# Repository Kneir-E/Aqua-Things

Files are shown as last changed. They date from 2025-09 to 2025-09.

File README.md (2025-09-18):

- **Aqua_Things_V2**
  - Arduino IDE platform  
  - Contains the latest version of the Main Device contents *(this is the latest that I can find, I lost copy to the actual final version)*
- **ESP8266_Calibration-Module**
  - Arduino IDE platform  
  - Contains the code for the Calibration Module
- **KiCad Files**
  - **3.1) ESP_Board_Test**  
    - KiCad Schematics for the main board of the device
  - **3.2) ESP8266_Calib_Module**  
    - KiCad Schematics for the calibration module board
  - **3.3) KiCad Extras-Libraries-etc**  
    - Libraries used for the creation of 3.1 and 3.2
- **Ignore the rest of the folders**
- **4) Old Version** → Ignore
- **5) Helper for testing - Lux-Web** → Ignore
- **6) Helper for testing - Temperature-Web** → Ignore

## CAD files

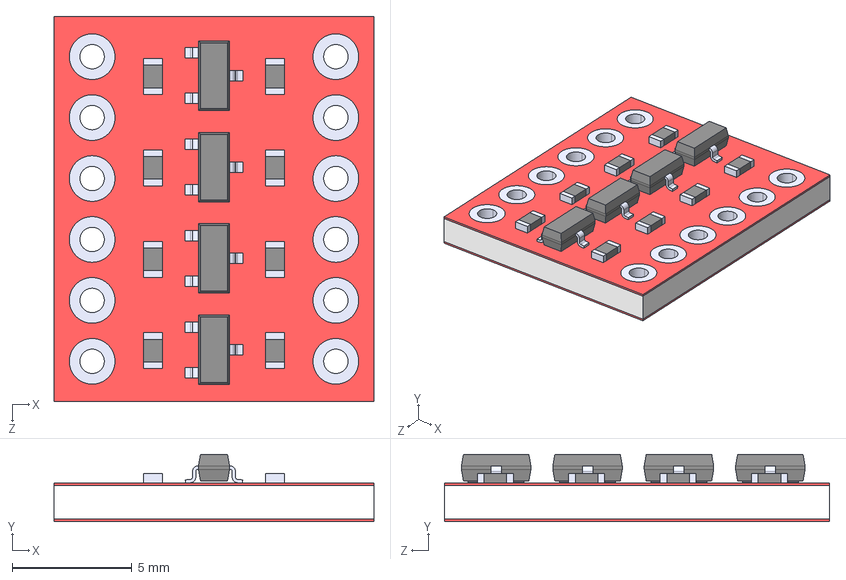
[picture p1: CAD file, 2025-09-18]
KiCad Files/KiCad Extras-Libraries-etc/BOB-12009/BOB-12009.step
13.3 x 2.80 x 16.1 mm

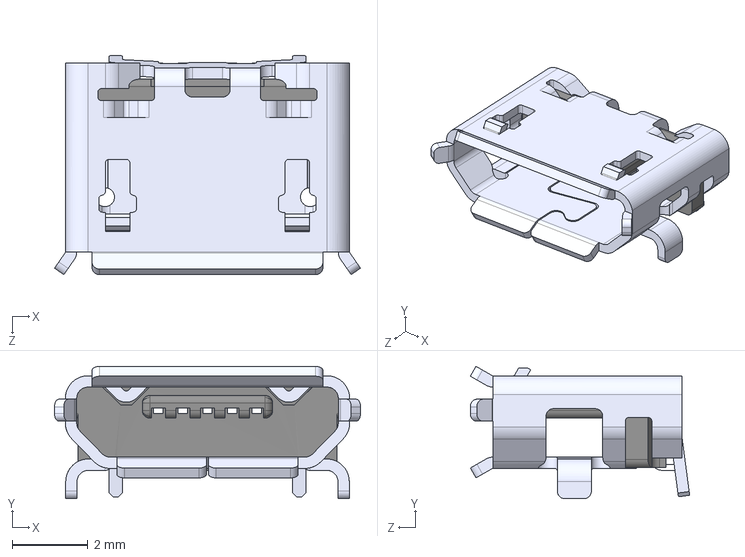
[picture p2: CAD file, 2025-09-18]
KiCad Files/KiCad Extras-Libraries-etc/MicroUSB/ZX62D-B-5P8.step
8.09 x 3.50 x 5.80 mm

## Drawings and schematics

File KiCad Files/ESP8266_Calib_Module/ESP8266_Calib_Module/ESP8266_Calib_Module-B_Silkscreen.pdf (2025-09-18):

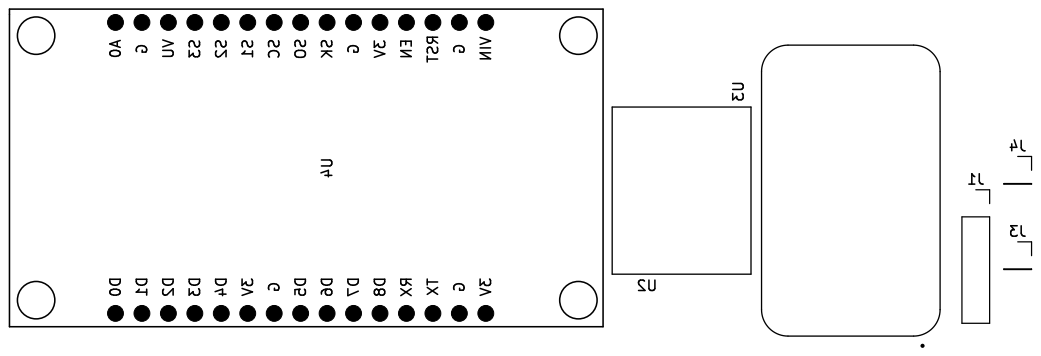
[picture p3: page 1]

J3 U4 SK RST D2 D3GRX VU 3V 3V D0 A0 SO D6 D7TX S2S1EN G G D5 S3SC D4 D8 VING D13V G

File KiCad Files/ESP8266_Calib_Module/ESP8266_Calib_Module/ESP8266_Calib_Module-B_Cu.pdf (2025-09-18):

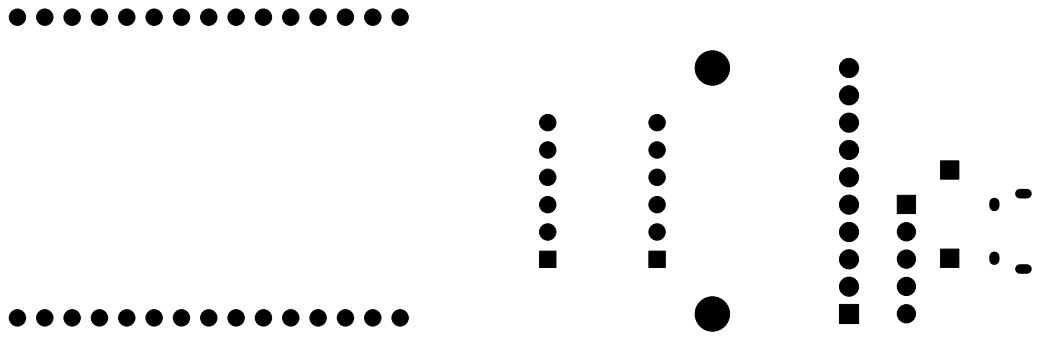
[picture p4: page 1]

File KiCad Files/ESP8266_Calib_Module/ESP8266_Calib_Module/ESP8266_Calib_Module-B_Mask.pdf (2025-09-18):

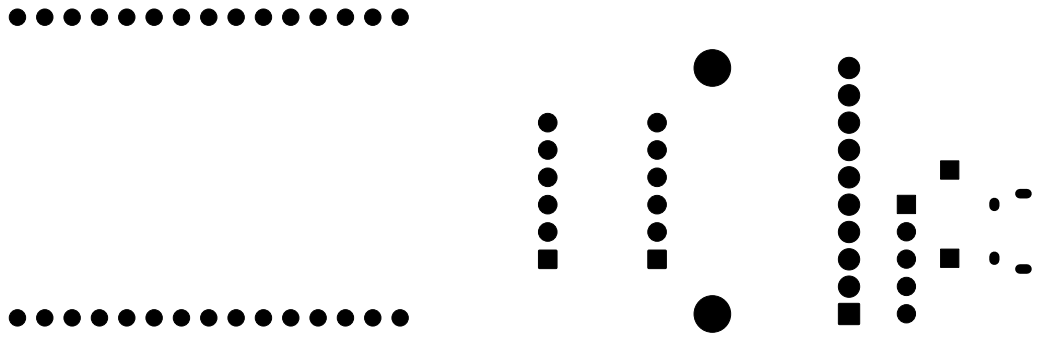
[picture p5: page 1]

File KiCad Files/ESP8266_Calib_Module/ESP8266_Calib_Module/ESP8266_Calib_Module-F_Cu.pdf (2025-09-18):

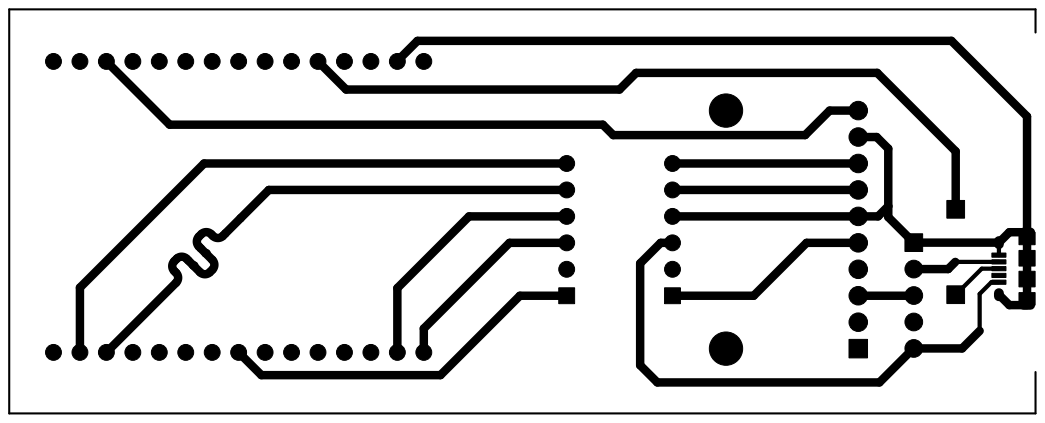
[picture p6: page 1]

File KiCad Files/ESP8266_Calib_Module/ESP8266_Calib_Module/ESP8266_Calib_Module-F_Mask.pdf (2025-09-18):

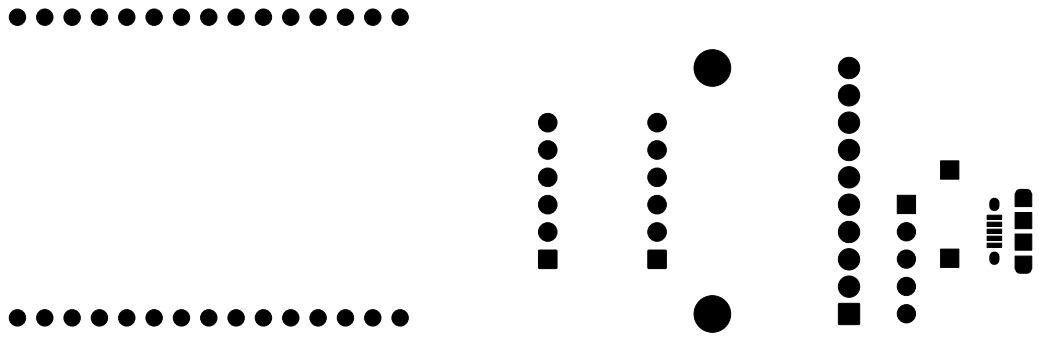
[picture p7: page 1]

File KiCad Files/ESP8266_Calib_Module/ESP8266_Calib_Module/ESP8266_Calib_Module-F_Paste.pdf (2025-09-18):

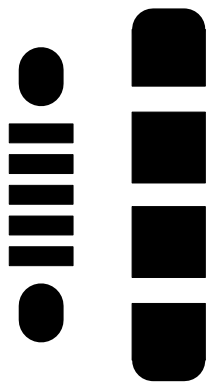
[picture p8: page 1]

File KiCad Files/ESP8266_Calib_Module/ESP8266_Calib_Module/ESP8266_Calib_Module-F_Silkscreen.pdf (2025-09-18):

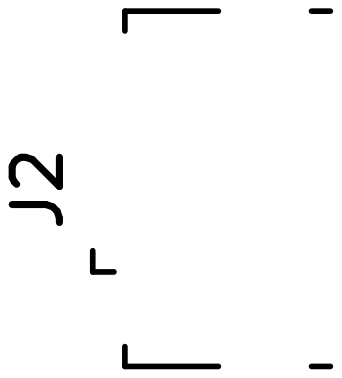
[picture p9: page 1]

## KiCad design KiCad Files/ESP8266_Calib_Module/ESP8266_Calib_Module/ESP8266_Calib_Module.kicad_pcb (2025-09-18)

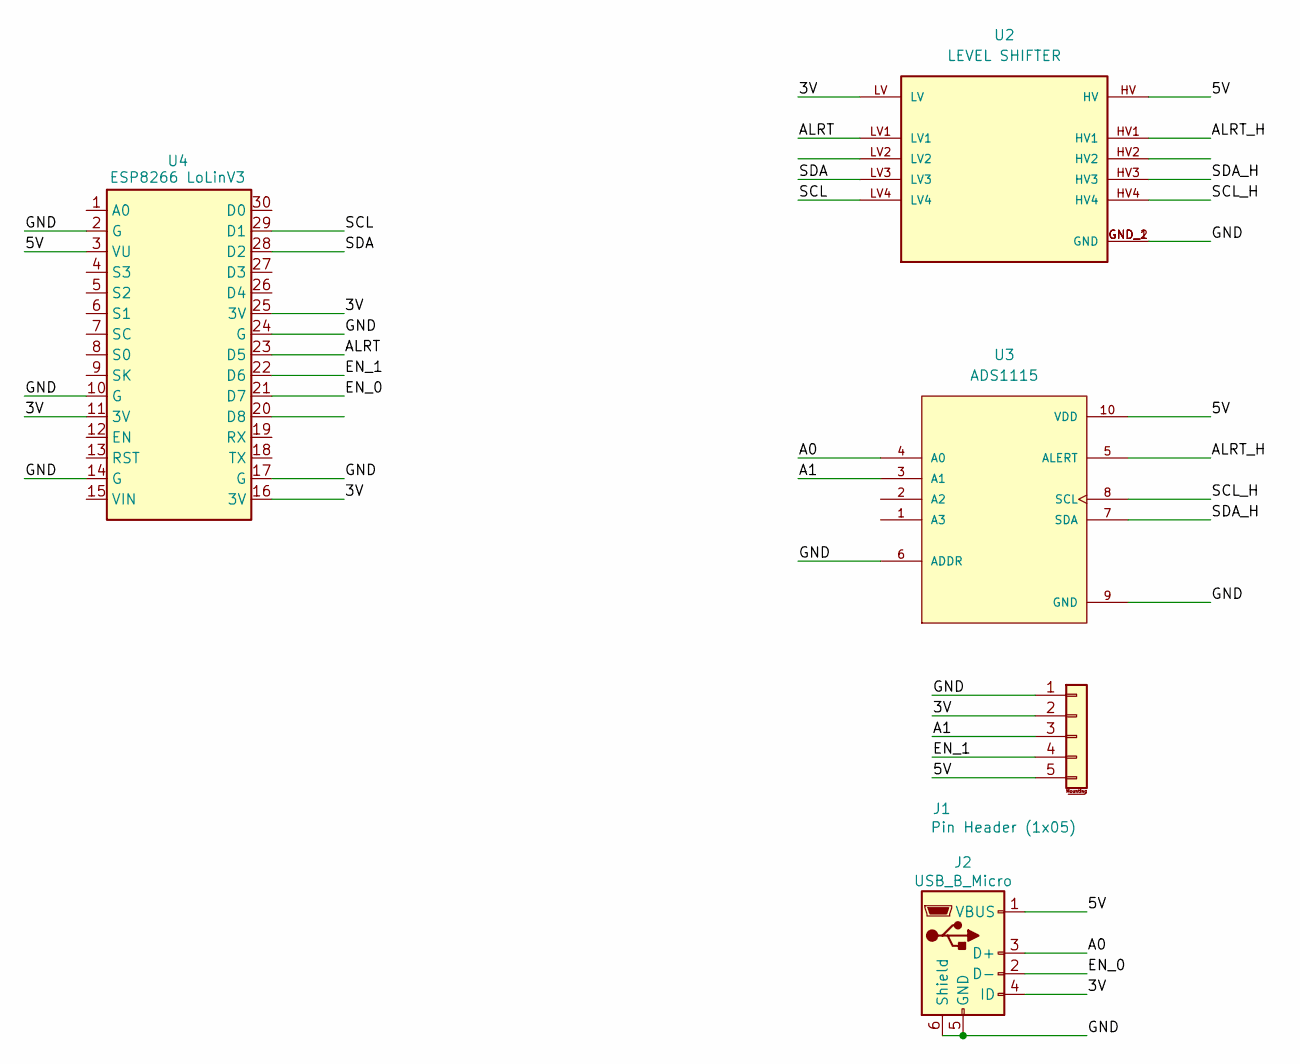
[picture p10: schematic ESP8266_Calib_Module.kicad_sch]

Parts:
J1: Pin Header (1x05); PinHeader_1x05_P2.54mm_Vertical
J2: USB_B_Micro; USB_Micro-B_Amphenol_10118194_Horizontal
U2: LEVEL SHIFTER; CONV_BOB-12009; PARTREV 01
U3: ADS1115; MODULE_ZC261500; PARTREV NA
U4: ESP8266 LoLinV3; NodeMCU-LoLinV3

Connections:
/3V: J1.2, J2.4 (ID), U2.LV, U4.11 (3V), U4.16 (3V), U4.25 (3V)
/5V: J1.5, J2.1 (VBUS), U2.HV, U3.10 (VDD), U4.3 (VU)
/A0: J2.3 (D+), U3.4 (A0)
/A1: J1.3, U3.3 (A1)
/ALRT: U2.LV1, U4.23 (D5)
/ALRT_H: U2.HV1, U3.5 (ALERT)
/EN_0: J2.2 (D-), U4.21 (D7)
/EN_1: J1.4, U4.22 (D6)
/GND: J1.1, J2.5 (GND), J2.6 (Shield), U2.GND_1 (GND), U2.GND_2 (GND), U3.6 (ADDR), U3.9 (GND), U4.2 (G), U4.10 (G), U4.14 (G), U4.17 (G), U4.24 (G)
/SCL: U2.LV4, U4.29 (D1)
/SCL_H: U2.HV4, U3.8 (SCL)
/SDA: U2.LV3, U4.28 (D2)
/SDA_H: U2.HV3, U3.7 (SDA)

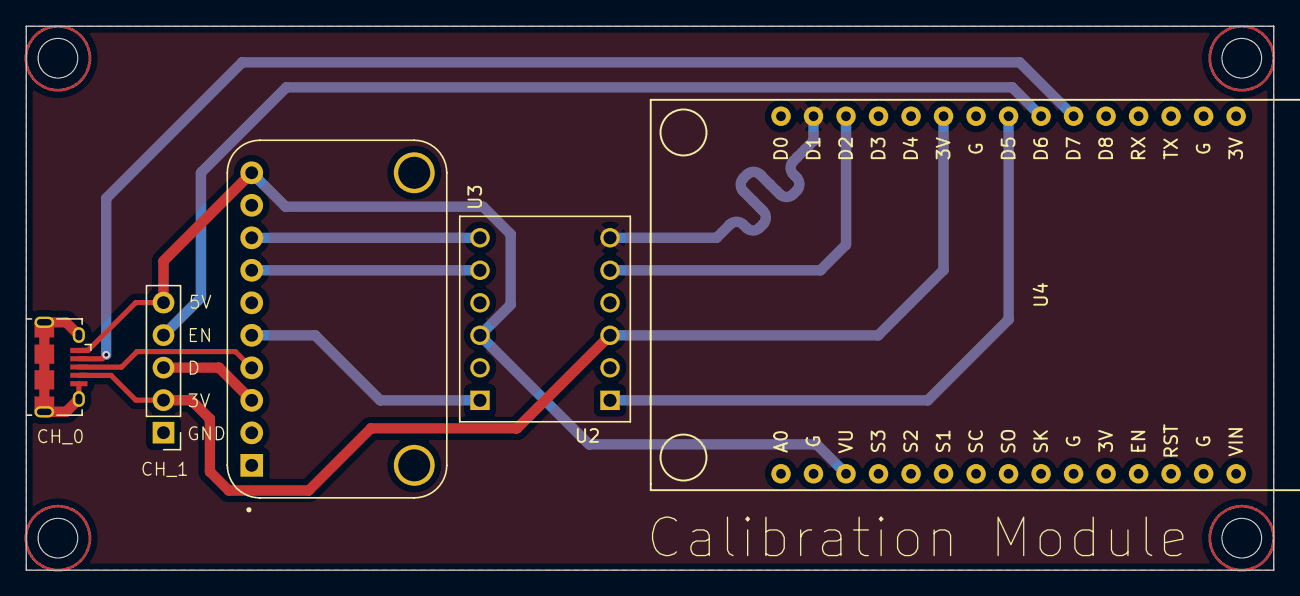
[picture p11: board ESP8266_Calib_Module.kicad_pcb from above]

Board: 2 copper layers, 97.5 x 42.5 mm, 5 parts (0 on the bottom side), 13 nets.

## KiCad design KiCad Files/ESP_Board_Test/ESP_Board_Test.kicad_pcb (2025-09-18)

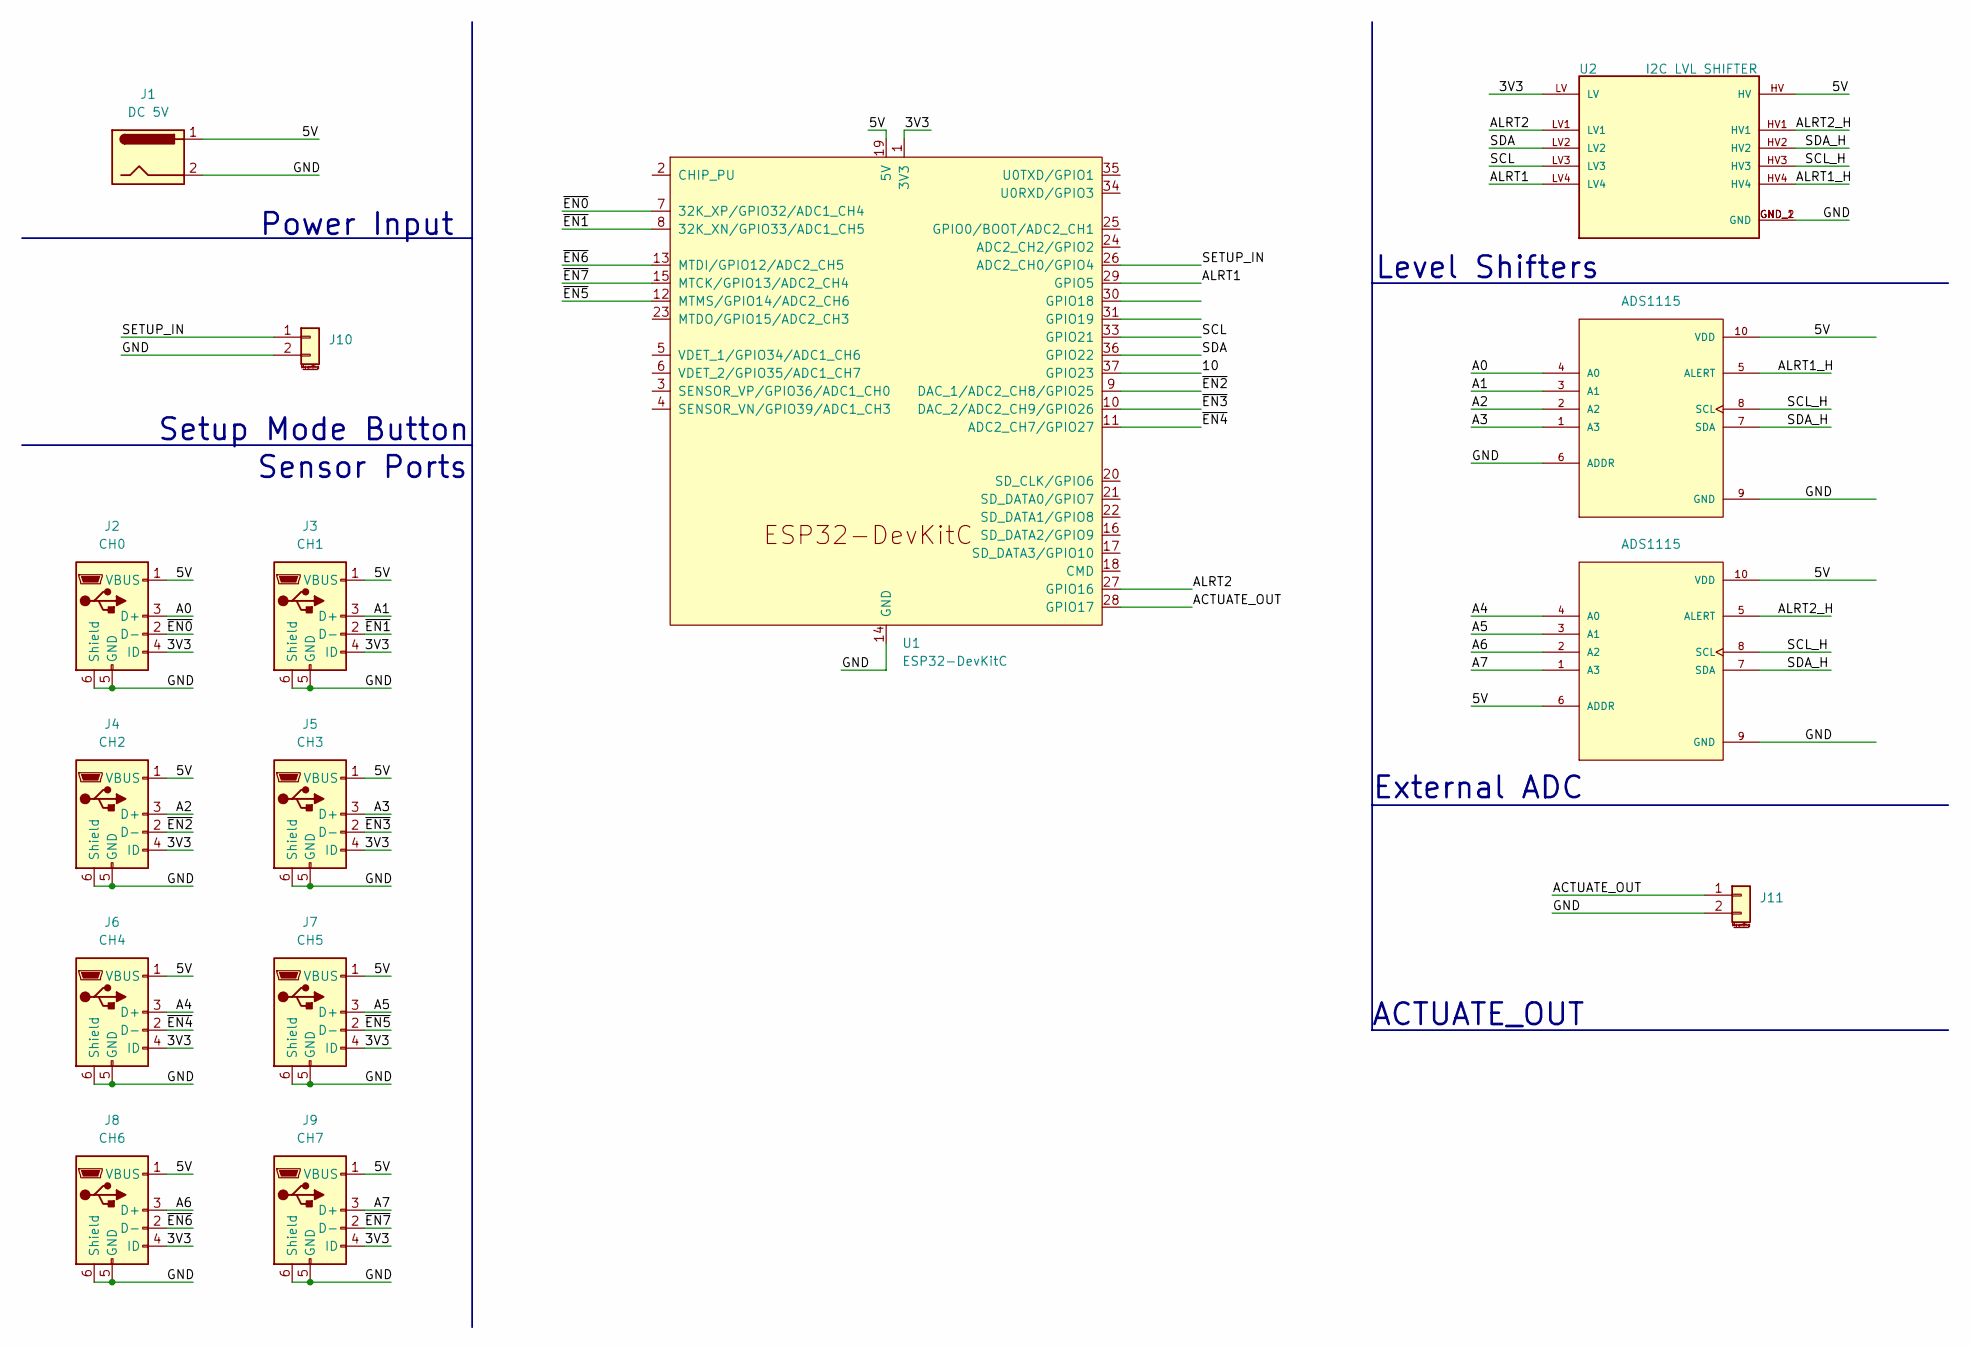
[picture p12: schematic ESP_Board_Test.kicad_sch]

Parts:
J1: DC 5V; BarrelJack_Horizontal
J2: CH0; USB_Micro-B_Amphenol_10118194_Horizontal
J3: CH1; USB_Micro-B_Amphenol_10118194_Horizontal
J4: CH2; USB_Micro-B_Amphenol_10118194_Horizontal
J5: CH3; USB_Micro-B_Amphenol_10118194_Horizontal
J6: CH4; USB_Micro-B_Amphenol_10118194_Horizontal
J7: CH5; USB_Micro-B_Amphenol_10118194_Horizontal
J8: CH6; USB_Micro-B_Amphenol_10118194_Horizontal
J9: CH7; USB_Micro-B_Amphenol_10118194_Horizontal
J10, J11: Pin Header; PinHeader_1x02_P2.54mm_Vertical
U1: ESP32-DevKitC
U2: I2C LVL SHIFTER; CONV_BOB-12009; PARTREV 01
U4, U5: ADS1115; MODULE_ZC261500; PARTREV NA

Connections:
/3V3: J2.4 (ID), J3.4 (ID), J4.4 (ID), J5.4 (ID), J6.4 (ID), J7.4 (ID), J8.4 (ID), J9.4 (ID), U1.1 (3V3), U2.LV
/5V: J1.1, J2.1 (VBUS), J3.1 (VBUS), J4.1 (VBUS), J5.1 (VBUS), J6.1 (VBUS), J7.1 (VBUS), J8.1 (VBUS), J9.1 (VBUS), U1.19 (5V), U2.HV, U4.10 (VDD), U5.6 (ADDR), U5.10 (VDD)
/10: U1.37 (GPIO23)
/A0: J2.3 (D+), U4.4 (A0)
/A1: J3.3 (D+), U4.3 (A1)
/A2: J4.3 (D+), U4.2 (A2)
/A3: J5.3 (D+), U4.1 (A3)
/A4: J6.3 (D+), U5.4 (A0)
/A5: J7.3 (D+), U5.3 (A1)
/A6: J8.3 (D+), U5.2 (A2)
/A7: J9.3 (D+), U5.1 (A3)
/ACTUATE_OUT: J11.1, U1.28 (GPIO17)
/ALRT1: U1.29 (GPIO5), U2.LV4
/ALRT1_H: U2.HV4, U4.5 (ALERT)
/ALRT2: U1.27 (GPIO16), U2.LV1
/ALRT2_H: U2.HV1, U5.5 (ALERT)
/GND: J1.2, J2.5 (GND), J2.6 (Shield), J3.5 (GND), J3.6 (Shield), J4.5 (GND), J4.6 (Shield), J5.5 (GND), J5.6 (Shield), J6.5 (GND), J6.6 (Shield), J7.5 (GND), J7.6 (Shield), J8.5 (GND), J8.6 (Shield), J9.5 (GND), J9.6 (Shield), J10.2, J11.2, U1.14 (GND), U1.32 (GND), U1.38 (GND), U2.GND_1 (GND), U2.GND_2 (GND), U4.6 (ADDR), U4.9 (GND), U5.9 (GND)
/SCL: U1.33 (GPIO21), U2.LV3
/SCL_H: U2.HV3, U4.8 (SCL), U5.8 (SCL)
/SDA: U1.36 (GPIO22), U2.LV2
/SDA_H: U2.HV2, U4.7 (SDA), U5.7 (SDA)
/SETUP_IN: J10.1, U1.26 (ADC2_CH0/GPIO4)
/~EN0: J2.2 (D-), U1.7 (32K_XP/GPIO32/ADC1_CH4)
/~EN1: J3.2 (D-), U1.8 (32K_XN/GPIO33/ADC1_CH5)
/~EN2: J4.2 (D-), U1.9 (DAC_1/ADC2_CH8/GPIO25)
/~EN3: J5.2 (D-), U1.10 (DAC_2/ADC2_CH9/GPIO26)
/~EN4: J6.2 (D-), U1.11 (ADC2_CH7/GPIO27)
/~EN5: J7.2 (D-), U1.12 (MTMS/GPIO14/ADC2_CH6)
/~EN6: J8.2 (D-), U1.13 (MTDI/GPIO12/ADC2_CH5)
/~EN7: J9.2 (D-), U1.15 (MTCK/GPIO13/ADC2_CH4)

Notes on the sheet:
Sensor Ports
Power Input
ACTUATE_OUT
External ADC
Level Shifters
Setup Mode Button

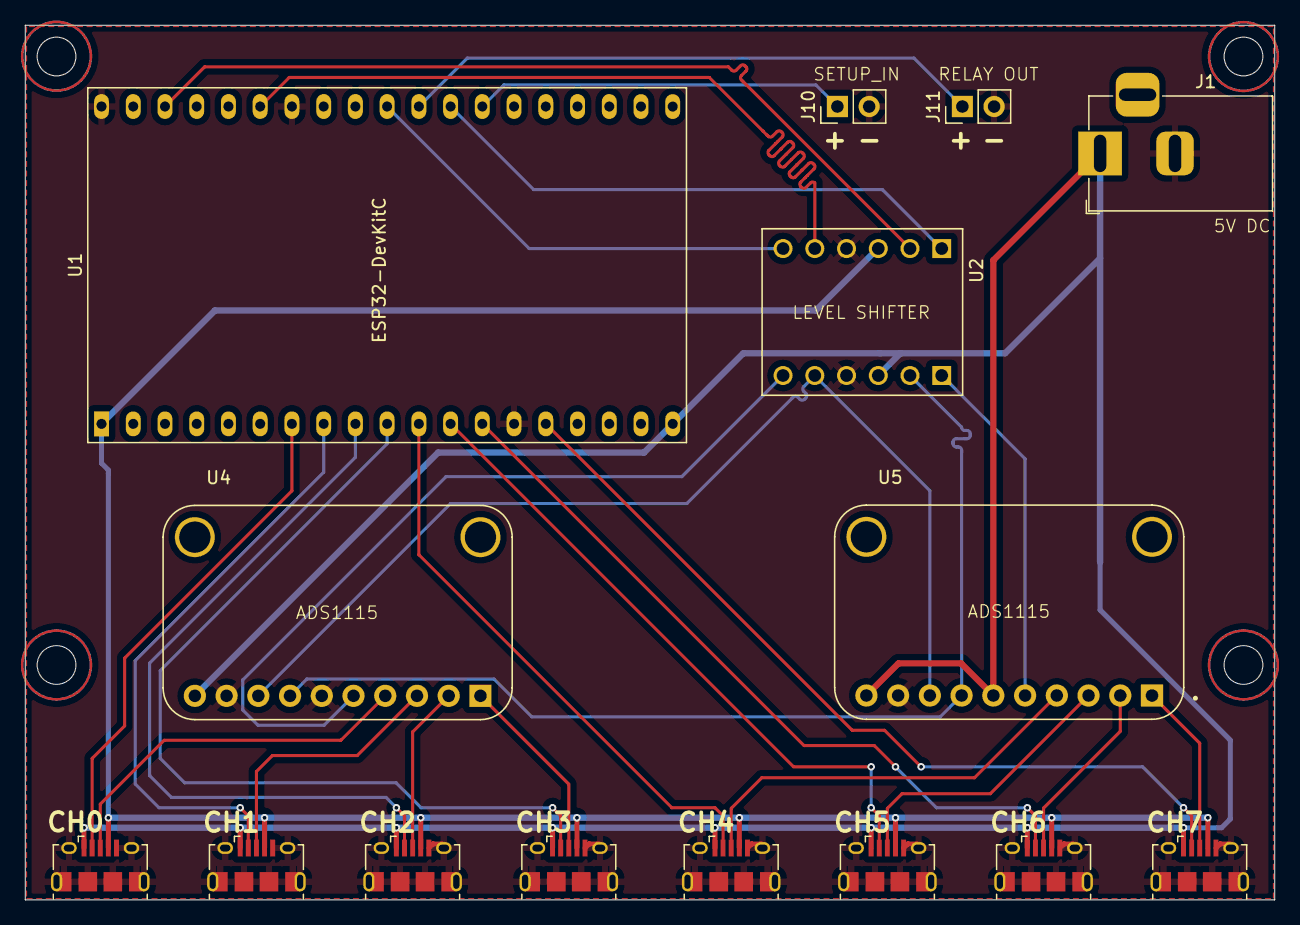
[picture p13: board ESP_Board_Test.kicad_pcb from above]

Board: 2 copper layers, 100.0 x 70.0 mm, 15 parts (0 on the bottom side), 29 nets.

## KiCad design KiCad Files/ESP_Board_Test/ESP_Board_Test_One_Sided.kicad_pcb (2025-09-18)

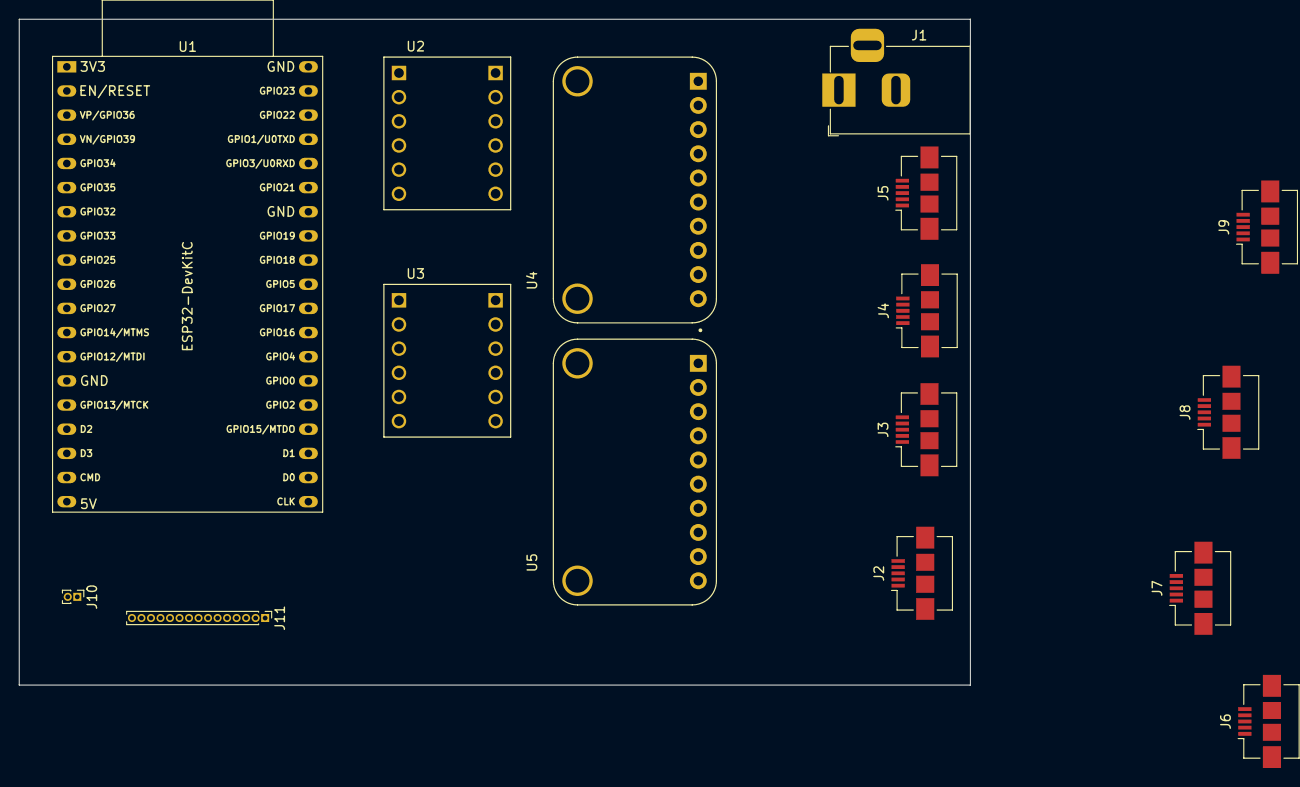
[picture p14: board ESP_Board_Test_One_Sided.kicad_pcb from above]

Board: 2 copper layers, 100.0 x 70.0 mm, 16 parts (0 on the bottom side), 34 nets, no tracks yet.

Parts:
J1: Barrel_Jack; BarrelJack_Horizontal
J2, J3, J4, J5, J6, J7, J8, J9: USB_B_Micro; USB_Micro-B_Amphenol_10104110_Horizontal
J10: Conn_01x02_MountingPin; PinHeader_1x02_P1.00mm_Vertical
J11: Conn_01x15_MountingPin; PinHeader_1x15_P1.00mm_Vertical
U1: ESP32-DevKitC
U2, U3: BOB-12009; CONV_BOB-12009
U4, U5: ZC261500; MODULE_ZC261500

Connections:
/1: J11.15, U1.7 (32K_XP/GPIO32/ADC1_CH4)
/2: J11.14, U1.8 (32K_XN/GPIO33/ADC1_CH5)
/3: J11.13, U1.13 (MTDI/GPIO12/ADC2_CH5)
/3V3: J2.1 (VBUS), J3.1 (VBUS), J4.1 (VBUS), J5.1 (VBUS), J6.1 (VBUS), J7.1 (VBUS), J8.1 (VBUS), J9.1 (VBUS), U1.1 (3V3), U2.LV, U3.LV
/4: J11.12, U1.15 (MTCK/GPIO13/ADC2_CH4)
/5: J11.11, U1.12 (MTMS/GPIO14/ADC2_CH6)
/5V: J1.1, J2.2 (D-), J3.2 (D-), J4.2 (D-), J5.2 (D-), J6.2 (D-), J7.2 (D-), J8.2 (D-), J9.2 (D-), U1.19 (5V), U2.HV, U3.HV, U4.10 (VDD), U5.10 (VDD)
/6: J11.10, U1.26 (ADC2_CH0/GPIO4)
/7: J11.9, U1.29 (GPIO5)
/8: J11.8, U1.30 (GPIO18)
/9: J11.7, U1.31 (GPIO19)
/10: J11.6, U1.37 (GPIO23)
/11: J11.5, U1.9 (DAC_1/ADC2_CH8/GPIO25)
/12: J11.4, U1.10 (DAC_2/ADC2_CH9/GPIO26)
/13: J11.3, U1.11 (ADC2_CH7/GPIO27)
/14: J11.2, U1.27 (GPIO16)
/15: J11.1, U1.28 (GPIO17)
/A0: J2.3 (D+), U4.4 (A0)
/A1: J3.3 (D+), U4.3 (A1)
/A2: J4.3 (D+), U4.2 (A2)
/A3: J5.3 (D+), U4.1 (A3)
/A4: J6.3 (D+), U5.4 (A0)
/A5: J7.3 (D+), U5.3 (A1)
/A6: J8.3 (D+), U5.2 (A2)
/A7: J9.3 (D+), U5.1 (A3)
/ADDR1_H: U2.HV2, U4.6 (ADDR)
/ADDR2_H: U3.HV4, U5.6 (ADDR)
/ALRT1_H: U2.HV1, U4.5 (ALERT)
/ALRT2_H: U3.HV3, U5.5 (ALERT)
/GND: J1.2, J2.5 (GND), J3.5 (GND), J4.5 (GND), J5.5 (GND), J6.5 (GND), J7.5 (GND), J8.5 (GND), J9.5 (GND), J10.2, U1.14 (GND), U1.32 (GND), U1.38 (GND), U2.GND_1 (GND), U2.GND_2 (GND), U3.GND_1 (GND), U3.GND_2 (GND), U4.9 (GND), U5.9 (GND)
/SCL: U1.33 (GPIO21), U3.LV2
/SCL_H: U3.HV2, U4.8 (SCL), U5.8 (SCL)
/SDA: U1.36 (GPIO22), U3.LV1
/SDA_H: U3.HV1, U4.7 (SDA), U5.7 (SDA)

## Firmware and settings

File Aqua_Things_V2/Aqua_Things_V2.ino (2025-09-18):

#include <WiFi.h>
#include <String.h>
#include "ConfigManager.h"
#include "ADS_functions.h"
#include "Preferences_functions.h"
#include "SocketClient.h"

// === Config Variables: Used in other header files ===
String STA_SSID = "";
String STA_PASS = "";
String STA_HOST = "";
String STA_PORT = "";
String AP_SSID = "";
String AP_PASS = "";
String PKT_HEAD = "";
String PKT_TAIL = "";
bool P0_ACTU_EN = false;
bool P1_ACTU_EN = false;
bool P2_ACTU_EN = false;
bool P3_ACTU_EN = false;
bool P4_ACTU_EN = false;
bool P5_ACTU_EN = false;
bool P6_ACTU_EN = false;
bool P7_ACTU_EN = false;
int P0_ACTU_L = -9999;  // Port 0 Actuation Value Low (actuate if measurement is below)
int P1_ACTU_L = -9999;  // Port 1                         ''
int P2_ACTU_L = -9999;  // Port 2                         ''
int P3_ACTU_L = -9999;  // Port 3                         ''
int P4_ACTU_L = -9999;  // Port 4                         ''
int P5_ACTU_L = -9999;  // Port 5                         ''
int P6_ACTU_L = -9999;  // Port 6                         ''
int P7_ACTU_L = -9999;  // Port 7                         ''
int P0_ACTU_H = 9999;   // Port 0 Actuation Value High (actuate if measurement is above)
int P1_ACTU_H = 9999;   // Port 1                         ''
int P2_ACTU_H = 9999;   // Port 2                         ''
int P3_ACTU_H = 9999;   // Port 3                         ''
int P4_ACTU_H = 9999;   // Port 4                         ''
int P5_ACTU_H = 9999;   // Port 5                         ''
int P6_ACTU_H = 9999;   // Port 6                         ''
int P7_ACTU_H = 9999;   // Port 7                         ''
uint64_t DEVICE_ADDRESS = 0;
int SETUP_STATUS = DEVICE_SETUP_INIT;

#define PIN_DET0 32
#define PIN_DET1 33
#define PIN_DET2 25
#define PIN_DET3 26
#define PIN_DET4 27
#define PIN_DET5 14
#define PIN_DET6 12
#define PIN_DET7 13
#define ACTUATE_DURATION 300000
#define PIN_ACTU 17
bool actuate_Trig = false;
unsigned long actuate_Start_Time = 0;
unsigned long prev_send_Time = 0;

// === External ADC Objects ===
int adsCh0 = -1;
int adsCh1 = -1;
int adsCh2 = -1;
int adsCh3 = -1;
int adsCh4 = -1;
int adsCh5 = -1;
int adsCh6 = -1;
int adsCh7 = -1;


void cl_Handle_Msg() {
  if(millis() - prev_send_Time<1000)  //If 1 second has not passed since previous send time
    return;
  else
    prev_send_Time=millis();
  if (cl.available()) {
    String rcvmsg = cl.readStringUntil('\n');
    Serial.print("Received: ");
    Serial.println(rcvmsg);
    rcvmsg.trim();    //remove leading or trailing white space
    String command = rcvmsg.substring(0, 7);
    if (command == "Actu_On") {
      actuate_Start();
      cl.println("Actuating");
    } else if (command == "ActuOff") {
      actuate_End();
      cl.println("Actuation End");
    } else if (command == "SetActu") {
      Serial.println("Received command: Set Actuation");
      bool success = true;
      String params = rcvmsg.substring(7, rcvmsg.length());
      // Serial.println("Params: " + params);
      // Serial.println(params.charAt(0) == '-');
      while (params.charAt(0) == '-') {
        //  "-CH0H:9999-CH0L:0000-CH1H:0000-"
        //  "0123456789"
        String tmp = params.substring(1, 5);
        String val = params.substring(6, 10);
        // Serial.println("tmp: " + tmp);
        // Serial.println("val: " + val);
        int valInt;
        if (!(isDigit(val.charAt(0)) && isDigit(val.charAt(1)) && isDigit(val.charAt(2)) && isDigit(val.charAt(3)))) {
          success = false;
          break;
        }
        valInt = val.toInt();
        if (tmp.charAt(4) == 'L' && valInt == 0) valInt = -9999;
        if (tmp == "CH0L") P0_ACTU_L = valInt;
        else if (tmp == "CH1L") P1_ACTU_L = valInt;
        else if (tmp == "CH2L") P2_ACTU_L = valInt;
        else if (tmp == "CH3L") P3_ACTU_L = valInt;
        else if (tmp == "CH4L") P4_ACTU_L = valInt;
        else if (tmp == "CH5L") P5_ACTU_L = valInt;
        else if (tmp == "CH6L") P6_ACTU_L = valInt;
        else if (tmp == "CH7L") P7_ACTU_L = valInt;
        else if (tmp == "CH0H") P0_ACTU_H = valInt;
        else if (tmp == "CH1H") P1_ACTU_H = valInt;
        else if (tmp == "CH2H") P2_ACTU_H = valInt;
        else if (tmp == "CH3H") P3_ACTU_H = valInt;
        else if (tmp == "CH4H") P4_ACTU_H = valInt;
        else if (tmp == "CH5H") P5_ACTU_H = valInt;
        else if (tmp == "CH6H") P6_ACTU_H = valInt;
        else if (tmp == "CH7H") P7_ACTU_H = valInt;
        else {
          success = false;
          break;
        }
        params = params.substring(10, params.length());
      }
      if (success) {
        Serial.println("Successfuly Updated Actuation");
        cl.println("Successful");
        pf_Update();
      } else {
        Serial.println("Unsuccessful Update in Actuation");
        cl.println("Unuccessful");
        pf_Get();
      }
    } else if (command == "SetAcEn") {
      Serial.println("Received command: Set Actuation");
      bool success = true;
      String params = rcvmsg.substring(7, rcvmsg.length());
      Serial.println("Params: " + params);
      Serial.println(params.charAt(0) == '-');
      while (params.charAt(0) == '-') {
        //  "-CH0:1-"
        //  "0123456"
        String chn = params.substring(1, 4);
        char val = params.charAt(5);
        Serial.println("chn: " + chn);
        Serial.println("val: " + val);
  
        bool result;
        if(val=='1') result = true;
        else if(val=='0') result = false;
        else{
          success = false;
          break;
        }
        if      (chn == "CH0") P0_ACTU_EN = result;
        else if (chn == "CH1") P1_ACTU_EN = result;
        else if (chn == "CH2") P2_ACTU_EN = result;
        else if (chn == "CH3") P3_ACTU_EN = result;
        else if (chn == "CH4") P4_ACTU_EN = result;
        else if (chn == "CH5") P5_ACTU_EN = result;
        else if (chn == "CH6") P6_ACTU_EN = result;
        else if (chn == "CH7") P7_ACTU_EN = result;
        else {
          success = false;
          break;
        }
        params = params.substring(6, params.length());
      }
      if (success) {
        Serial.println("Successfuly Updated Actuation Enable");
        cl.println("Successful");
        pf_Update();
      } else {
        Serial.println("Unsuccessful Update in Actuation Enable");
        cl.println("Unuccessful");
        pf_Get();
      }
    }
  }
  String msg = String("{ ")
               + "\"CH0\": " + String(adsCh0) + ", " + "\"DET0\": " + String(digitalRead(PIN_DET0) == LOW) + ", "
               + "\"CH1\": " + String(adsCh1) + ", " + "\"DET1\": " + String(digitalRead(PIN_DET1) == LOW) + ", "
               + "\"CH2\": " + String(adsCh2) + ", " + "\"DET2\": " + String(digitalRead(PIN_DET2) == LOW) + ", "
               + "\"CH3\": " + String(adsCh3) + ", " + "\"DET3\": " + String(digitalRead(PIN_DET3) == LOW) + ", "
               + "\"CH4\": " + String(adsCh4) + ", " + "\"DET4\": " + String(digitalRead(PIN_DET4) == LOW) + ", "
               + "\"CH5\": " + String(adsCh5) + ", " + "\"DET5\": " + String(digitalRead(PIN_DET5) == LOW) + ", "
               + "\"CH6\": " + String(adsCh6) + ", " + "\"DET6\": " + String(digitalRead(PIN_DET6) == LOW) + ", "
               + "\"CH7\": " + String(adsCh7) + ", " + "\"DET7\": " + String(digitalRead(PIN_DET7) == LOW) + ", "
               + "\"ActuStat\": " + String(actuate_Trig) + "} ";

  cl.println(msg);
  Serial.println("Sent to Server: " + msg);
}

void config_Callback_On_Submit() {
  Serial.println("Callback Triggered on Submit");
  pf_Update();
  WiFi.softAPdisconnect();
  WiFi.disconnect(false, true);
  Serial.println(WiFi.status());
  Serial.println(WiFi.getMode());
  wifi_Init();
}

void port_Init() {
  Serial.println("Port Initialized");
  pinMode(PIN_DET0, INPUT_PULLUP);
  pinMode(PIN_DET1, INPUT_PULLUP);
  pinMode(PIN_DET2, INPUT_PULLUP);
  pinMode(PIN_DET3, INPUT_PULLUP);
  pinMode(PIN_DET4, INPUT_PULLUP);
  pinMode(PIN_DET5, INPUT_PULLUP);
  pinMode(PIN_DET6, INPUT_PULLUP);
  pinMode(PIN_DET7, INPUT_PULLUP);
  pinMode(PIN_ACTU, OUTPUT);
  digitalWrite(PIN_ACTU, HIGH);
}

void handle_Actu() {
  if (actuate_Trig) {
    if (millis() - actuate_Start_Time >= ACTUATE_DURATION) {
      actuate_End();
    }
    return;
  }
  if (P0_ACTU_EN && adsCh0 <= P0_ACTU_L) actuate_Start();
  if (P1_ACTU_EN && adsCh1 <= P1_ACTU_L) actuate_Start();
  if (P2_ACTU_EN && adsCh2 <= P2_ACTU_L) actuate_Start();
  if (P3_ACTU_EN && adsCh3 <= P3_ACTU_L) actuate_Start();
  if (P4_ACTU_EN && adsCh4 <= P4_ACTU_L) actuate_Start();
  if (P5_ACTU_EN && adsCh5 <= P5_ACTU_L) actuate_Start();
  if (P6_ACTU_EN && adsCh6 <= P6_ACTU_L) actuate_Start();
  if (P7_ACTU_EN && adsCh7 <= P7_ACTU_L) actuate_Start();

  if (P0_ACTU_EN && adsCh0 >= P0_ACTU_H) actuate_Start();
  if (P1_ACTU_EN && adsCh1 >= P1_ACTU_H) actuate_Start();
  if (P2_ACTU_EN && adsCh2 >= P2_ACTU_H) actuate_Start();
  if (P3_ACTU_EN && adsCh3 >= P3_ACTU_H) actuate_Start();
  if (P4_ACTU_EN && adsCh4 >= P4_ACTU_H) actuate_Start();
  if (P5_ACTU_EN && adsCh5 >= P5_ACTU_H) actuate_Start();
  if (P6_ACTU_EN && adsCh6 >= P6_ACTU_H) actuate_Start();
  if (P7_ACTU_EN && adsCh7 >= P7_ACTU_H) actuate_Start();
}

void actuate_Start() {
  if (actuate_Trig != true) {
    Serial.println("Actuation Started");
    digitalWrite(PIN_ACTU, LOW);
    actuate_Trig = true;
    actuate_Start_Time = millis();
  }
}

void actuate_End() {
  Serial.println("Actuation Ended");
  digitalWrite(PIN_ACTU, HIGH);
  actuate_Trig = false;
  actuate_Start_Time = 0;
}

void setup() {
  Serial.begin(115200);

  pf_Init();    // Retrieve Config Variables from ROM and store in RAM
  ads_Init();   // Initialize extenal ADC
  port_Init();  // Initialize port detection pins and actuation pin

  conf_Init(cl_Stop, config_Callback_On_Submit);  // Initialize Config Mode
                                                  // =======================ADD CALLBACKS... SHOULD BE AFTER WIFI===========================
                                                  // on trigger: close client
                                                  // on submit: pf_Update(), wifi_Init()

  if (is_Setup_Done == DEVICE_SETUP_NONE)  // IF DEVICE SETUP HAS NOT BEEN DONE
    __conf_trig_flag = true;               // Trigger Config Mode
}

void loop() {
  if (is_Setup_Done != DEVICE_SETUP_DONE) {  // IF DEVICE SETUP HAS NOT BEEN DONE
    Serial.println("No Setup Found. Entering Initial Setup Mode");
    config_Mode_Loop(9999, true);  // Enter Config Mode with no Expiry Time.
    delay(1000);
    return;  // Do Nothing else
  } else
    config_Mode_Loop();  // Required function for setup mode async - process config mode flags and functions


  if (__conf_enabled) {  // IF IN SETUP MODE
    // CODE TO DO WHILE IN CONFIG MODE

  } else if (!__conf_enabled) {  // IF IN OPERATION MODE

    // if WiFi not Connected, Connect WiFi
    if (WiFi.status() != WL_CONNECTED)
      wifi_Init();

    // if WiFi connected but Client not connected, Connect Client
    if (WiFi.status() == WL_CONNECTED && !cl.connected())
      cl_Connect();

    // if WiFi connected and Client connected, Handle comms with client
    else if (WiFi.status() == WL_CONNECTED && cl.connected()) {
      cl_Handle_Msg();
    }
  }

  // ========== FOREGROUND ROUTINE ==========
  Serial.println("Foreground Routine");
  // ALWAYS DO IN ANY MODE
  ads_Reconnect();
  ads_Read_All();  // Read all channels and update global variables
  handle_Actu();
  if (conf_Reset_Flag) {
    Serial.println("Clearing Config");
    pf_Reset();
    Serial.println("Clear Complete. Restarting...");
    ESP.restart();
  }
  // delay(500);
}

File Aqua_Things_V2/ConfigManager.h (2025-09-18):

#ifndef AP_CONFIG_FUNCTIONS_H
#define AP_CONFIG_FUNCTIONS_H

#include "Config_WebFiles.h"
#include "Config_StringHandling.h"
#include <AsyncTCP.h>
#include <ESPAsyncWebServer.h>

#ifndef CONFIG_INT_PIN
#define CONFIG_INT_PIN 4
#endif

AsyncWebServer __conf_server(80);
unsigned long __conf_SrvStartTime;    // The time that the __conf_server has been started
bool    __conf_enabled = false;          // Config Server current status
bool    __conf_trig_flag = false;        // true if Config Server button has been pressed
bool    __conf_successful_input = false;   // true if user successfully inputted data, false if user exitted
bool    conf_Reset_Flag = false;
String  __conf_scanned_networks = "";

typedef void (*CallbackFunction)();
CallbackFunction __conf_Call_On_Trigger = nullptr;
CallbackFunction __conf_Call_On_Submit = nullptr;

extern String STA_SSID;
extern String STA_PASS;
extern String STA_HOST;
extern String STA_PORT;
extern String AP_SSID;
extern String AP_PASS;
extern String PKT_HEAD;
extern String PKT_TAIL;
extern int SETUP_STATUS;

void __conf_AP_Init();
void __conf_Mode_Enable();
void __conf_Mode_Disable();
void __conf_Server_Init();
void __conf_Scan_Networks();
void config_Mode_Loop(int expire_time_seconds, bool is_No_Expiry);
void __conf_ISR();
void conf_Init(CallbackFunction callBeforeTrigger, CallbackFunction callOnSubmit);
bool __config_Process_Paste(String data);


void __conf_AP_Init(){
  WiFi.disconnect(false, true);
  WiFi.mode(WIFI_AP);
  WiFi.softAP(AP_SSID, AP_PASS);
  Serial.println("Access Point Started");
  Serial.print("IP Address: ");
  Serial.println(WiFi.softAPIP());
}

void __conf_Mode_Enable(){
  // disconnect Client
  // disconnect STA

  __conf_AP_Init();
  __conf_Server_Init();
  __conf_server.begin();
  __conf_SrvStartTime = millis();
  __conf_enabled = true;
}

void __conf_Mode_Disable(){
  WiFi.disconnect(true, true);
  __conf_server.reset();
  __conf_enabled = false;
  Serial.println("Server Ended");
  if (__conf_Call_On_Submit != nullptr) {
    __conf_Call_On_Submit();
  }
  // create SubmitSuccess variable to check
  // check and consume it on main
}

void __conf_Server_Init(){
  __conf_server.on("/", HTTP_GET, [](AsyncWebServerRequest* request) {
    Serial.println("Received HTTP GET /");
    request->redirect("/main-menu");
  });

  __conf_server.on("/main-menu", HTTP_GET, [](AsyncWebServerRequest* request) {
    Serial.println("Received HTTP GET /main-menu");
    request->send(200, "text/html", main_menu_html);
  });

  __conf_server.on("/edit-wifi", HTTP_GET, [](AsyncWebServerRequest* request) {
    Serial.println("Received HTTP GET /edit-wifi");
    request->send(200, "text/html", edit_wifi_html);
  });

  __conf_server.on("/edit-all", HTTP_GET, [](AsyncWebServerRequest* request) {
    Serial.println("Received HTTP GET /edit-all");
    request->send(200, "text/html", edit_all_html);
  });

  __conf_server.on("/paste", HTTP_GET, [](AsyncWebServerRequest* request) {
    Serial.println("Received HTTP GET /paste");
    request->send(200, "text/html", paste_html);
  });

  __conf_server.on("/reset-confirm", HTTP_GET, [](AsyncWebServerRequest* request) {
    Serial.println("Received HTTP GET /reset-confirm");
    request->send(200, "text/html", reset_confirm_html);
  });

  __conf_server.on("/exit", HTTP_GET, [](AsyncWebServerRequest* request) {
    Serial.println("Received HTTP GET /exit");
    if(SETUP_STATUS==1)  __conf_Mode_Disable();
    else request->redirect("/main-menu");
  });

  __conf_server.on("/style", HTTP_GET, [](AsyncWebServerRequest* request) {
    request->send(200, "text/css", style_css);
  });

  __conf_server.onNotFound([](AsyncWebServerRequest* request){
    request->send(200, "text/html", not_found_html);
  });

  __conf_server.on("/error", HTTP_GET, [](AsyncWebServerRequest* request){
    request->send(200, "text/html", error_html);
  });

  __conf_server.on("/ssid-scan", HTTP_GET, [](AsyncWebServerRequest* request){
    String response = __conf_scanned_networks;
    request->send(200, "text/plain", response);
  });

  __conf_server.on("/update-wifi", HTTP_GET, [](AsyncWebServerRequest* request) {
    Serial.println("Received: HTTP_GET /update-wifi");
    SETUP_STATUS = 1;

    String _sta_ssid  = "";
    String _sta_pass  = "";
    String _sta_host  = "";
    String _sta_port  = "";

    _sta_ssid = request->getParam("STA_SSID")->value();
    _sta_pass = request->getParam("STA_PASS")->value();
    _sta_host = request->getParam("STA_HOST")->value();
    _sta_port = request->getParam("STA_PORT")->value();

    if(_sta_ssid != "")   STA_SSID = _sta_ssid;
    if(_sta_pass != "")   STA_PASS = _sta_pass;
    if(_sta_host != "")   STA_HOST = _sta_host;
    if(_sta_port != "")   STA_PORT = _sta_port;

    // request->send(200, "text/html", success_html);
    request->redirect("/exit");
  });

  __conf_server.on("/update-all", HTTP_GET, [](AsyncWebServerRequest* request) {
    Serial.println("Received: HTTP_GET /update-all");
    SETUP_STATUS = 1;
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

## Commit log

2024-09-10 Initial Commit
    Uploaded Calibration Module and Main Unit
2025-09-18 V2 and Calibration Module Update
2025-09-18 Hardware FIles
    [BOB-12009.step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]
